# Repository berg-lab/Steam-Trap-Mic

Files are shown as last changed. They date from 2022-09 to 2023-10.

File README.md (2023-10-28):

# Franklin Energy Steam Project - Stream Trap Monitor Firmware

## Overview
We are building a device which will monitor ultrasonic auditory data of steam traps involved with heating systems. Upon completion, the goal of this device is to be able to recognize what a failing steam trap sounds like, and broadcast an alert when a fault is detected. By catching these faults early on, we can save energy that would otherwise be wasted through silent, incorrect temperature regulation caused by the broken piece. This repo itself holds the firmware for this steam trap accessory, along with some test files and schematics of the accessory itself.

## Navigation
- **[firmware](firmware/)** - directory for all source files of the device firmware, as well as some test files.
- **[py](py/)** - directory for all python helper scripts, such as reading and processing serial data.
- **[schematic](schematic/)** - directory for visual documentation on the device's custom board design.

## Contributing
For contributing to the source code of this project, please create your own branch and use a pull request to get these changes onto the main branch. To begin development of your own local branch, run the following git CLI commands from terminal:
```
git clone https://github.com/berg-lab/Steam-Trap-Mic.git
cd Steam-Trap-Mic
git checkout -b your_branch_name
```
From here, you can make local changes to your branch and experiment with different code. Once the repo is in a good state to save and checkpoint, add all of your changes into a commit and push them to your branch on the remote repository:
```
git add .
git commit -m "commit message describing changes here"
git push -u origin your_branch_name
```
These new changes will now be visible to everyone with access to the repo on the web. This process should be done any time a significant change is made! _Note: the -u flag sets the designated push location as the default for the current local branch, so any subsequent pushes can be done with just the command_ `git push`.

To get your changes onto the main branch, please use a pull request. **AVOID PUSHING DIRECTLY TO MAIN.** You can open a pull request on Github by going to the "Pull requests" tab in the repo and clicking "New pull request." From here, select "main" for base and your branch for compare. Making sure all merge conflicts are resolved, and click "Create pull request." Once this pull request is reviewed, it can be merged to the main branch of production.

Lastly, because there are multiple people working on the repository, there will be changes made to main often, which need to be reflected on your local branch. You can bring these new changes onto your branch with one command: `git pull`. **ALWAYS PULL BEFORE YOU PUSH.** This will avoid merge conflicts which can occur if your pull requests do not contain the most recent changes made to main.

## Deployment
To upload the firmware onto the device, make sure it is connected to your computer through a COM port. In the Arduino IDE, open the project and select this port, which should be labeled with "Moteino M0" under `Tools > Port`. Finally, click "Upload" to transfer the code to the device and begin running the main loop.

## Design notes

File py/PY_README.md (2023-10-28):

# Python Helper Scripts

## Overview
This directory is home to all python helper scripts for debugging the steam traps.

## Descriptions
- **serial_reader.py**: a short script to read the output of serial monitor when connected to a Moteino that is continuously sending voltage readings. This data is plotted and displayed to the screen and can be used to view a general picture of the waveform heard by the Moteino's ultrasonic mic. Required command line argument is `COM_PORT`, which designates which serial port to listen to. Optional command line argument is `duration` (specified by "-d" flag) which designates how many seconds to listen to the serial data, default value is 5. The example below listens to serial port COM5 for 10 seconds:
```
python3 serial_reader.py COM5 -d 10
```

- **wav_converter.py**: a short script to convert a given .wav file into a CSV designating the analog output of the sound in volts. The data is plotted and displayed for a sanity check. After the data is exported to CSV, this CSV can be imported into EasyWaveX to later be emulated with a function generator. To keep things tidy while running this script, place all .wav files into the `/steam_sounds` directory, and export to the `/csvs` directory. Required command line arguments are `input_file` and `output_file`, which designate the .wav file to read and .csv file to export, respectively. The .csv file does not need to exist before running the script, this is simply the name of the file you want to create. The example below reads the file "sample_in.wav" located in the `\steam_sounds` directory and creates a CSV of analog output named "sample_out.csv" located in the `\csvs` directory:
```
python3 wav_converter.py steam_sounds/sample_in.wav csvs/sample_out.csv
```

## Dependencies
These scripts require Python 3. Each of these must be installed to the PYTHONPATH which can be done with pip, as detailed in the [Quick Start](#quick-start) section below. See the dependencies below for each file:
- serial_reader.py
    - matplotlib
    - pyserial
- wav_converter.py
    - audiosegment (repo [here]("https://github.com/MaxStrange/AudioSegment"))
    - matplotlib

## Quick Start
First, make sure the following dependency is installed to your system by running the commands below in a Unix style terminal:
```
sudo apt-get update
sudo apt-get install sox
```

Next you can use the pip install to install the python-specific packages from PyPI:
```
python3 -m pip3 install --upgrade pip3
pip3 install matplotlib pyserial
pip3 install --user audiosegment
```

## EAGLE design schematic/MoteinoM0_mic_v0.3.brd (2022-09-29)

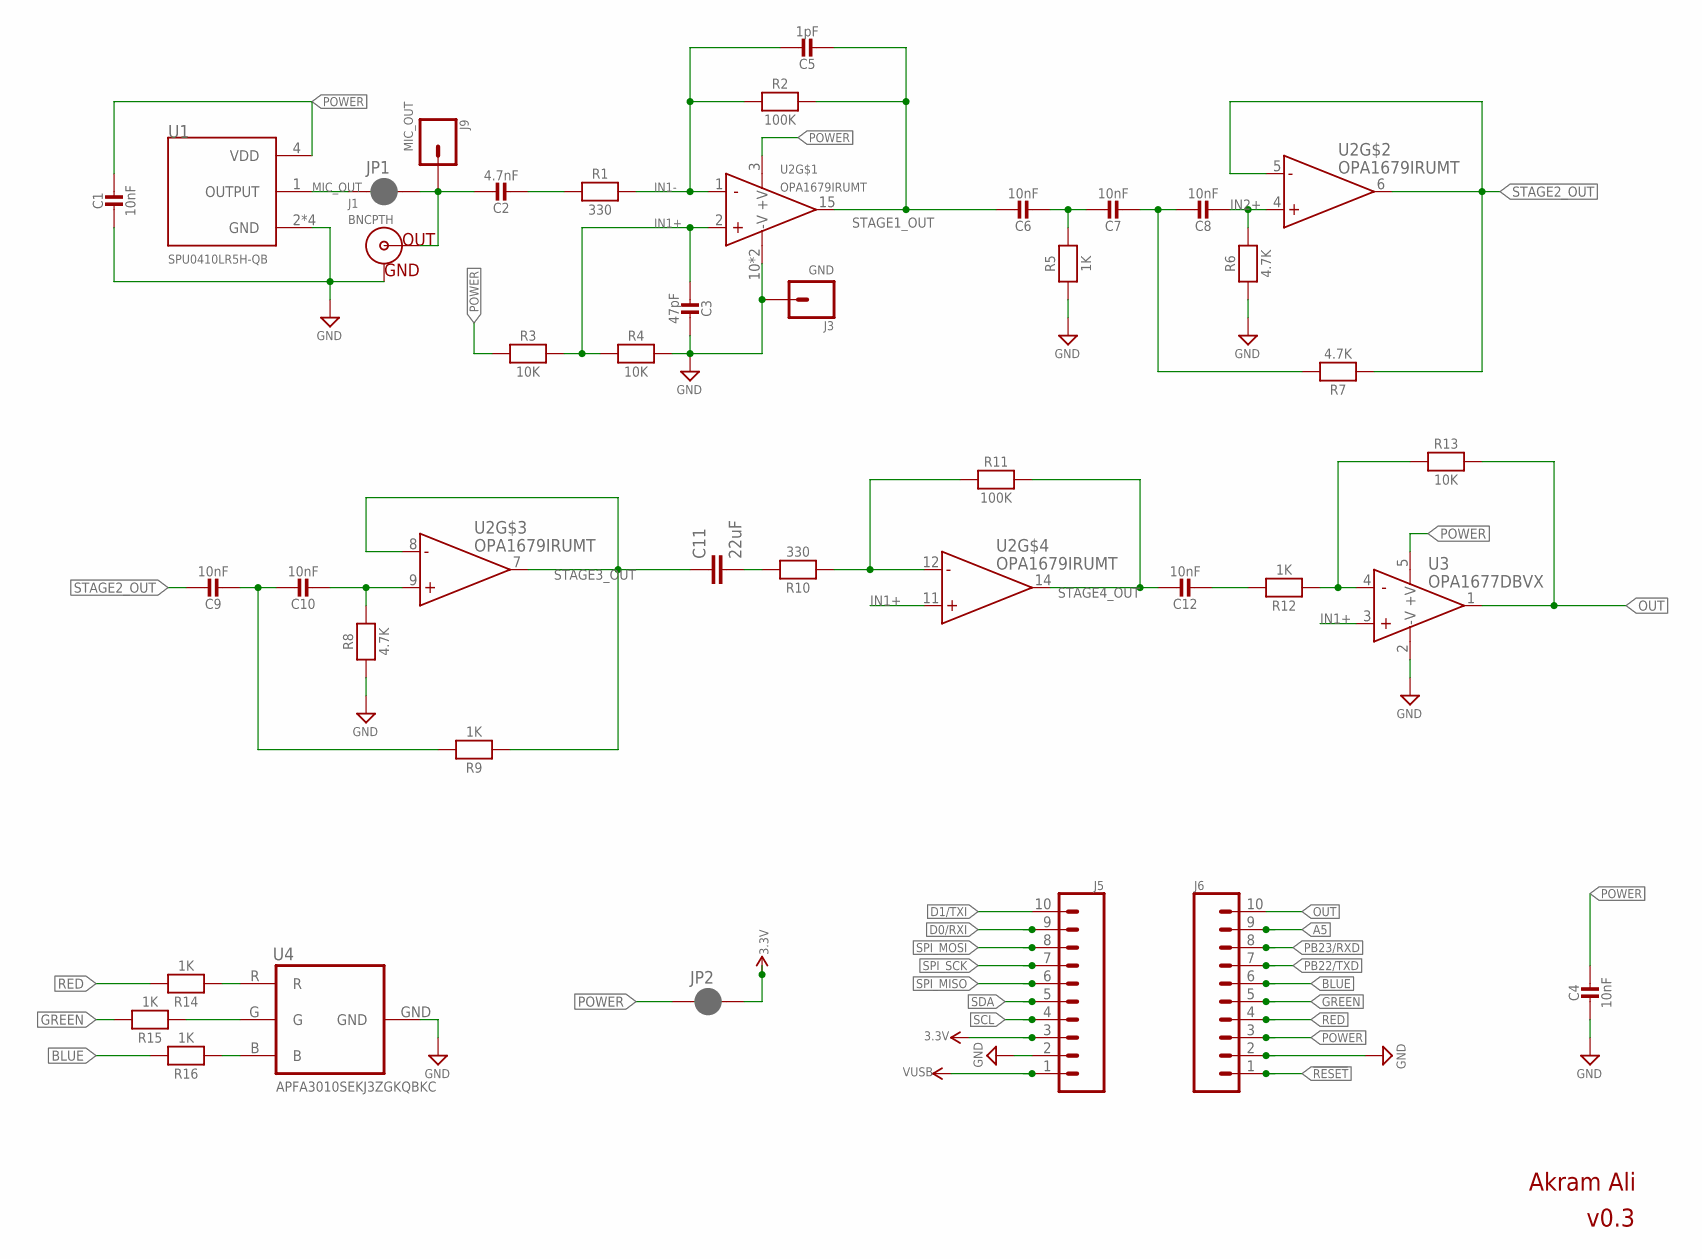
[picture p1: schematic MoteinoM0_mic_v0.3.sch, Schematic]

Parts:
C1, C4, C6, C7, C8, C9, C10, C12: 10nF; MICROBUILDER__0402MP; MPN GRM155R71H104KE14J
C2: 4.7nF; MICROBUILDER__0402MP; MPN GRM155R71H104KE14J
C3: 47pF; MICROBUILDER__0402MP; MPN GRM155R71H104KE14J
C5: 1pF; MICROBUILDER__0402MP; MPN GRM155R71H104KE14J
C11: 22uF; 0805
J1: BNCPTH; BNC
J3: GND; 1X01
J5, J6: CONN_10NO_SILK_PTH_FEMALE; 1X10_NO_SILK
J9: MIC_OUT; 1X01
JP1, JP2: JUMPER-SMT_2_NC_PASTE_SILK; SMT-JUMPER_2_NC_PASTE_SILK
R1, R10: 330; MICROBUILDER__0402MP; MPN RC0402FR-074K7P
R2, R11: 100K; MICROBUILDER__0402MP; MPN RC0402FR-074K7P
R3, R4, R13: 10K; MICROBUILDER__0402MP; MPN RC0402FR-074K7P
R5, R9, R12, R14, R15, R16: 1K; MICROBUILDER__0402MP; MPN RC0402FR-074K7P
R6, R7, R8: 4.7K; MICROBUILDER__0402MP; MPN RC0402FR-074K7P
U1: SPU0410LR5H-QB; XDCR_SPU0410LR5H-QB
U2: OPA1679IRUMT; QFN65P400X400X80-17N
U3: OPA1677DBVX; SOT23-5
U4: APFA3010SEKJ3ZGKQBKC; SMD-RA-4

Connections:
3.3V: J5.3, JP2.2
!RESET: J6.1
A5: J6.9
BLUE: J6.6, R16.2
D0/RXI: J5.9
D1/TXI: J5.10
GND: C1.2, C3.1, C4.2, J1.GND, J3.1, J5.2, J6.2, R4.2, R5.1, R6.1, R8.1, U1.2 (GND), U1.3 (GND), U1.5 (GND), U1.6 (GND), U2.10 (-V), U2.17 (-V), U3.2 (-V), U4.GND
GREEN: J6.5, R15.2
IN1+: C3.2, R3.2, R4.1, U2.2 (+IN), U2.11 (+IN), U3.3 (+IN)
IN1-: C5.1, R1.2, R2.1, U2.1 (-IN)
IN2+: C8.2, R6.2, U2.4 (+IN)
MIC_OUT: C2.1, J1.S (OUT), J9.1, JP1.2
unnamed: C9.2, C10.1, R9.2
unnamed: C6.2, C7.1, R5.2
unnamed: C7.2, C8.1, R7.2
unnamed: C2.2, R1.1
unnamed: R14.1, U4.R
unnamed: C10.2, R8.2, U2.9 (+IN)
unnamed: C11.2, R10.2
unnamed: R15.1, U4.G
unnamed: R10.1, R11.1, U2.12 (-IN)
unnamed: R16.1, U4.B
unnamed: C12.2, R12.2
unnamed: R12.1, R13.1, U3.4 (-IN)
unnamed: JP1.1, U1.1 (OUTPUT)
OUT: J6.10, R13.2, U3.1 (OUT)
PB22/TXD: J6.7
PB23/RXD: J6.8
POWER: C1.1, C4.1, J6.3, JP2.1, R3.1, U1.4 (VDD), U2.3 (+V), U3.5 (+V)
RED: J6.4, R14.2
SCL: J5.4
SDA: J5.5
SPI_MISO: J5.6
SPI_MOSI: J5.8
SPI_SCK: J5.7
STAGE1_OUT: C5.2, C6.1, R2.2, U2.15 (OUT)
STAGE2_OUT: C9.1, R7.1, U2.5 (-IN), U2.6 (OUT)
STAGE3_OUT: C11.1, R9.1, U2.7 (OUT), U2.8 (-IN)
STAGE4_OUT: C12.1, R11.2, U2.14 (OUT)
VUSB: J5.1

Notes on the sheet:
v0.3
Akram Ali

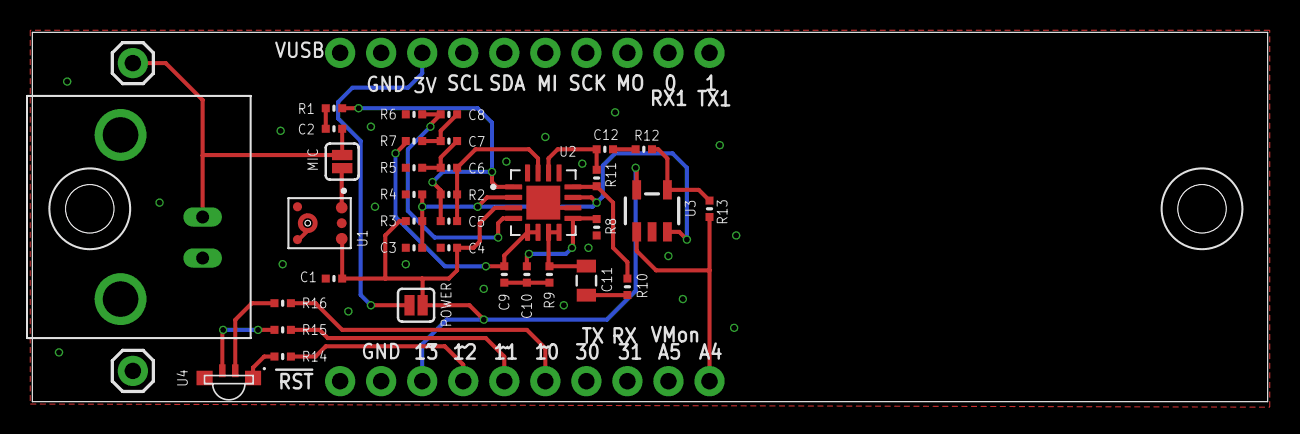
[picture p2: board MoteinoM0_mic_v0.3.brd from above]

Board: 2 copper layers, 76.4 x 22.9 mm, 39 parts (0 on the bottom side), 28 nets.

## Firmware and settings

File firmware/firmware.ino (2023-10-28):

#include <stdint.h>
#include "common.h"
#include "globals.h"

// Setup (ran once at reset)
void setup() {
  // Serial Initialization
  Serial.begin(SERIAL_BAUD);
  delay(3000);
  Serial.println("Serial initialized!");

  // initialize pins input/output
  pinMode(LED_BUILTIN, OUTPUT);
  // analogReadResolution(12); //use 12-bit resolution for analog reading
  Serial.println("PINS initialized!");

  // MAC address configuration
  // Flash.deviceSetup();

  // Radio Initialization
  Radio.initializeRadio();
  Serial.println("Radio Initialized!");
  Radio.sendConfigPacket(3);
  Serial.println("Config Packet Sent!");

  // Timer Initialization
  Timer.clearFlag();
}

uint16_t pre_temp;
uint16_t post_temp;

// Loop (runs forever)
void loop() {
  if(Timer.timerExpired()) {

    // clear interrupt flag
    Timer.clearFlag();

    // Measure temperature
    sendTemp();

    // Set new 10 minute timer
    Timer.setTimer(0,10,0);
    Serial.println("Alarm set, going to sleep now.");
    Timer.goSleep();
  }
}

// Methods
void Blink(int DELAY_MS)
{
  pinMode(LED_BUILTIN, OUTPUT);
  digitalWrite(LED_BUILTIN,HIGH);
  delay(DELAY_MS/2);
  digitalWrite(LED_BUILTIN,LOW);
  delay(DELAY_MS/2);
}

float toCelcius(float resist_value) {
  float steinhart = 0;
  // convert the value to resistance
  steinhart = 1023 / resist_value - 1;
  steinhart = SERIESRESISTOR / steinhart;

  // convert to degrees Celcius
  steinhart = steinhart / THERMISTORNOMINAL;     // (R/Ro)
  steinhart = log(steinhart);                  // ln(R/Ro)
  steinhart /= BCOEFFICIENT;                   // 1/B * ln(R/Ro)
  steinhart += 1.0 / (TEMPERATURENOMINAL + 273.15); // + (1/To)
  steinhart = 1.0 / steinhart;                 // Invert
  steinhart -= 273.15;                         // convert absolute temp to C
  return steinhart;
}

void sendTemp(void) {
  pre_temp = (int)(toCelcius(analogRead(THERMISTOR_PIN_0))*100);
  post_temp = (int)(toCelcius(analogRead(THERMISTOR_PIN_1))*100);
  Blink(2000);
  Serial.println(pre_temp); Serial.println(post_temp);
  Radio.sendDataPacket(pre_temp, post_temp, (uint8_t) 0);
}

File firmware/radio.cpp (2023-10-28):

//=========================================================================================================
// radio.cpp - Implements a radio interface to the gateway
//=========================================================================================================
#include "radio.h"
#include "globals.h"
#include "common.h"

// Define radio communication variables
#define WITHRFM69
#ifdef WITHRFM69
  #include <RFM69.h>
  #include <RFM69_ATC.h>

  #ifdef ENABLE_ATC
    RFM69_ATC radio;
  #else
    RFM69 radio;
  #endif
  #define RADIO_FREQ RF69_915MHZ
#endif
#define IS_RFM69HW
//=========================================================================================================
// maps a structure onto a buffer named "raw"
//=========================================================================================================
#define map_struct(t,m) t& m=*(t*)raw
//=========================================================================================================

//=========================================================================================================
// device_config_t  - This is a config packet we transmit to the gateway when we are in configuration mode
//
// stm_trap_data_t  - This is a telemetry packet we transmit to the gateway every time we wake up from our
//                    sleep cycle (or when the Serial Server "transmit" command is received)
//  
// from_gateway_t   - This contains bit flags that inform the node on what fields need to be updated.
//                    If no bits are set, it's an acknowledgement message
//=========================================================================================================
struct device_config_t
{
    uint8_t     pkt_type;
    uint8_t     version;
    uint8_t     device_type;
    uint16_t    firmware_version;
    uint8_t     uid[8];
};

struct stm_trap_telemetry_t
{
    uint8_t     pkt_type;
    uint8_t     version;
    uint16_t    pre_temperature;
    uint16_t    post_temperature;
    uint8_t     error_byte;
    uint8_t     transaction_id;
};

struct from_gateway_t
{
    uint8_t     pkt_type;
    uint8_t     tasks_bit_field;
    uint8_t     network_id;
    uint16_t    node_id;
    uint8_t     encryption_key[16];
};
//=========================================================================================================

// radio packet type
enum pkt_type_t  : uint8_t
{
    CONFIG_PACKET       = 0,
    TELEMETRY_PACKET    = 1,
    RESPONSE_PACKET     = 2
};

//=========================================================================================================
// initializeRadio() - Start up radio function and report if error occurs
//=========================================================================================================
void CRadio::initializeRadio() {

    #ifdef WITHRFM69
        // if hardware permits, try radio object initialization
        if (!radio.initialize(RADIO_FREQ, NODE_ID, NETWORK_ID))
            Error.raise_error(RADIO_ERR);
        else {
            Error.clear_error(RADIO_ERR);
            Serial.println("Radio initialized!");
        }
        // if hardware permits, try setting high power
        #ifdef IS_RFM69HW
            radio.setHighPower(); //uncomment only for RFM69HW!
        #endif
    #endif

    // assign encription key to radio object for later transmission
    radio.encrypt(ENCRYPT_KEY);
    radio.sleep();

    // start the transaction id at 1
    transaction_id = 1;
}
//=========================================================================================================


//=========================================================================================================
// sendDataPacket() - Loads data into packet and transmits it over the radio
//=========================================================================================================
void CRadio::sendDataPacket(uint16_t pre_temp, uint16_t post_temp, uint8_t error_byte)
{
    stm_trap_telemetry_t telemetry;
    bool success = false;

    // Fill in the data in the telemetry packet
    telemetry.pkt_type          = TELEMETRY_PACKET;
    telemetry.version           = TELEMETRY_VERSION;
    telemetry.pre_temperature   = pre_temp;
    telemetry.post_temperature  = post_temp;
    telemetry.error_byte        = error_byte;
    telemetry.transaction_id    = transaction_id;

    // Attempt to send a packet to the gateway 3 times and wait for response
    for (int attempts = 0; attempts < 3; ++attempts)
    {
        // send the packet
        radio.send(GATEWAY_ID, &telemetry, sizeof(telemetry));

        // start a 1 second timer
        Timer.setTimer(1,0,0);

        // sit in a loop for 1 second until a response is received
        while (!Timer.timerExpired())
        {
            // if we receive a response
            if (radio.receiveDone())
            {
                // handle response and break out
                handleIncomingPacket(radio.DATA);
                success = true;
                break;
            }
        }
        Timer.clearFlag();
        if (success) {
            // blink slow to show packet sent
            for (int x=0; x<3; x++) {
                digitalWrite(LED_BUILTIN, HIGH);
                delay(250);
                digitalWrite(LED_BUILTIN, LOW);
                delay(250);
            }
            break;
        }
    }

    // increment transaction ID and reset it to 1 if it overflows
    if (++transaction_id == 0) transaction_id = 1;
}
//=========================================================================================================
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

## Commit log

2022-09-29 adding schematic illustrations
    [MoteinoM0_mic_v0.3.brd, MoteinoM0_mic_v0.3.sch]
2022-10-10 config: fixing microphone pin
    [common.h]
2023-08-21 fixing serial port malfunction on win 10
    [firmware.ino]
2023-08-25 updated code for temperature version
2023-08-28 fixed class methods and added serial print statements
    [firmware.ino, radio.cpp]
2023-09-18 implemented thermistor with radio
2023-10-19 defining max value for the ADC
2023-10-19 fixing C errors in timer function
2023-10-19 fixing some syntax errs in firmware
    [firmware.ino]
2023-10-28 fixing timer discrepancy

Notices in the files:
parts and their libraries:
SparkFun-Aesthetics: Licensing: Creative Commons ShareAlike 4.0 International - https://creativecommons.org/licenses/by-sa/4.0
